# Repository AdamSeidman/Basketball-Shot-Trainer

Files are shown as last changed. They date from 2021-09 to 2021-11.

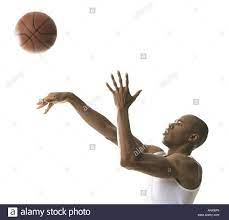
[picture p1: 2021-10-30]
Code/Python_Code/Images/image2.jpg

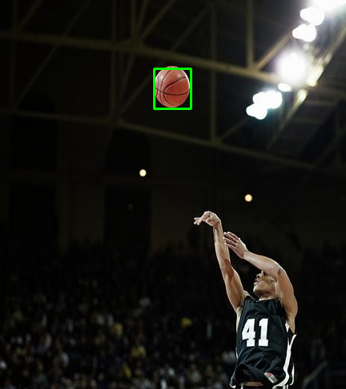
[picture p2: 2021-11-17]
Code/Python_Code/Images/success.PNG

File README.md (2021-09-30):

# Basketball Shot Trainer
**Multidisciplinary Senior Design Project for RIT.** &nbsp; _(P21014)_

&ensp;&ensp;The Unified Sports Basketball Shot Trainer analyzes various parameters of a person’s body while shooting a basketball to determine what can be changed to improve the player’s shooting percentage. It analyzes parameters such as arm trajectory, direction of shot, angle of shot, shooting efforts, etc.

&ensp;&ensp;The goals of the project are to design a device that can accomplish the task of analyzing the parameters as described above and correlate them to shooting performance based on court position.  The desired end-result is a working portable, battery-operated prototype with non-intrusive body sensors that can be modeled for production. The device is to be used by Unified Sports to improve the shot accuracy of basketball players. There are no concerns for intellectual property.

&ensp;&ensp;The aim of this project is to provide an approach to developing players' basketball skills through giving the players tangible feedback on their form and shooting performance. Given that our customer is the Special Olympics Unified Sports league, which gives kids with special needs opportunities to grow, a system that provides feedback for improvement can ultimately help them develop better self-confidence in their abilities.

_See our [Confluence Page](https://wiki.rit.edu/pages/viewpage.action?spaceKey=P21014&title=Project+Overview)_  
&nbsp;

### Our Team: 
| **Member** | **Major** | **Role** | **Contact** |
| --- | :---: | :---: | :---: |
| Matthew Fuss | Electrical Engineering | App Development/Sensor Integration, Documentation | mjf3758@rit.edu |
| Trevor Hess | Mechanical Engineering | Team Leader, Project Management, CAD | tdh8765@rit.edu |
| Mercy Chado | Biomedical Engineering | Systems Engineering, Communication | mxc2597@rit.edu |
| Kaitlyn Pohler | Electrical Engineering | Purchasing | kap3922@rit.edu |
| Adam Seidman | Computer Engineering | Embedded Systems, CAD | ajs1551@rit.edu |
| John Bui | Industrial Engineering | Lean Implementation | jcb2832@rit.edu |

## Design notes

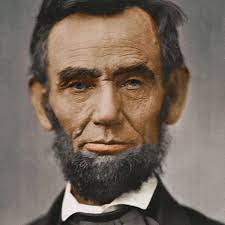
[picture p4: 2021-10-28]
Code/Python_Code/Images/Unknown.jpg

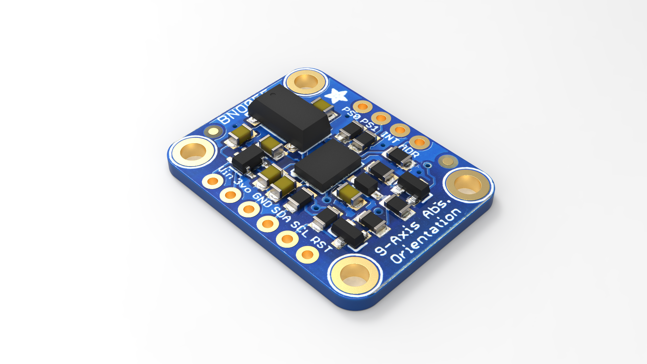
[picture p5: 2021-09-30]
CAD/Adafruit BNO055/Renderings/Render2.png

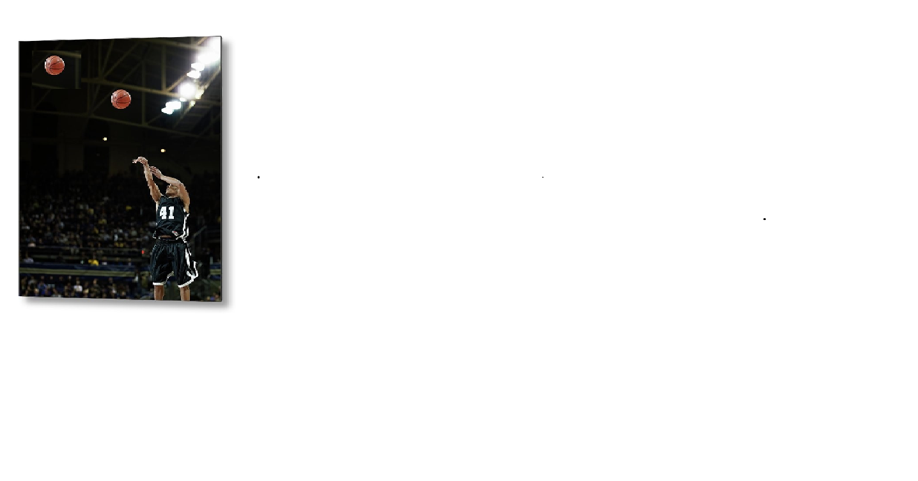
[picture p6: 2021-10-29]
Code/Python_Code/two_balls.png

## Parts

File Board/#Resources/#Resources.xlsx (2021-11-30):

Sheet: Links
BLE Board | https://www.adafruit.com/product/2995
Google Doc | https://docs.google.com/document/d/1nqfAvCQWS0-UqFdw947gi0GywAVGIpcRjdkHSJIjVWc/edit#
Older Feather Pinout | https://cdn-learn.adafruit.com/assets/assets/000/046/196/original/Feather_M0_Basic_Proto_v2.2.pdf?1504805559
Uno (Testing) | https://store-usa.arduino.cc/products/arduino-uno-rev3
Older Feather Power | https://learn.adafruit.com/adafruit-feather-m0-basic-proto/power-management
IMU Info Page | https://learn.adafruit.com/adafruit-bno055-absolute-orientation-sensor/pinouts

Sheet: Relevant Parts
6 pin female | https://www.digikey.com/en/products/detail/amphenol-icc-fci/91614-306ALF/1536169
8 pin female | https://www.digikey.com/en/products/detail/amphenol-icc-fci/91601-308LF/1535152
12 pin female | https://www.digikey.com/en/products/detail/amphenol-icc-fci/91601-412ALF/2713716
6 pin male | https://www.digikey.com/en/products/detail/amphenol-icc-fci/77311-401-06LF/1657857
8 pin male | https://www.digikey.com/en/products/detail/amphenol-icc-fci/68002-208HLF/1878507
12 pin male | (2 6 pins)
10k resistor 0603 | https://www.digikey.com/en/products/detail/nte-electronics-inc/SR1-0603-610/11655708
RGB LED | https://www.digikey.com/en/products/detail/harvatek-corporation/B3803FCH-20C001112U1930/13588742
RGB Resistor | https://www.digikey.com/en/products/detail/panasonic-electronic-components/ERJ-PB3D2000V/6212984
PWR LED | https://www.digikey.com/en/products/detail/american-opto-plus-led/L171L-GC/12325425 | https://www.digikey.com/en/products/detail/sunled/XZCDGK53W-8VF/10449775
PWR Resistor | --- | https://www.digikey.com/en/products/detail/susumu/RR0816P-152-D/432189
Coin Cell Holder | https://www.digikey.com/en/products/detail/keystone-electronics/1027/49724
Coin Cell |  | cr2330 | https://www.digikey.com/en/products/detail/panasonic-bsg/CR2330/107117
Switch | https://www.digikey.com/en/products/detail/nidec-copal-electronics/CFS-0102TA/12142641
4.7uF Cap_16V | https://www.digikey.com/en/products/detail/avx-corporation/TAJA475M016RNJ/808808
1uF Cap 0603 | https://www.digikey.com/en/products/detail/murata-electronics/GRM185R61E105KA12D/5026383
0.1uF Cap 0603 | https://www.digikey.com/product-detail/en/walsin-technology-corporation/0603B104K101CT/1292-1392-1-ND/9355396
5v Regulator | https://www.digikey.com/en/products/detail/texas-instruments/LM1117IMPX-5-0-NOPB/3440161
6 pin IMU cable
6 Pin IMU board | 1 6pin female & male
6 pin IMU Crimps?
6-cable | https://www.digikey.com/en/products/detail/tensility-international-corp/30-00510/6245003
28-wire-red | https://www.digikey.com/en/products/detail/tensility-international-corp/30-01782/13998326
28-wire-black | https://www.digikey.com/en/products/detail/tensility-international-corp/30-01783/13998447

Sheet: Order 1
Vendor: | Digikey |  |  |  | Total: | $46.67
Description | Part # | Price | Quantity | Total |  | Link
6 Pin Female Header | 609-6018-ND | $1.01 | 4 | $4.04 |  | https://www.digikey.com/en/products/detail/amphenol-icc-fci/91601-306LF/1535606
8 Pin Female Header | 609-4966-ND | $1.29 | 2 | $2.58 |  | https://www.digikey.com/en/products/detail/amphenol-icc-fci/91601-308LF/1535152
12 Pin Female Header | 609-4414-1-ND | $2.65 | 2 | $5.30 |  | https://www.digikey.com/en/products/detail/amphenol-icc-fci/91601-412ALF/2713716
6 Pin Male Header | 609-3403-ND | $0.48 | 10 | $4.84 |  | https://www.digikey.com/en/products/detail/amphenol-icc-fci/68001-206HLF/1658017
8 Pin Male Header | 609-10129378-908002BLF-ND | $0.24 | 2 | $0.48 |  | https://www.digikey.com/en/products/detail/amphenol-icc-fci/10129378-908002BLF/7915950
10K Resistor | YAG2321CT-ND | $0.06 | 20 | $1.18 |  | https://www.digikey.com/en/products/detail/yageo/RT0603FRE0710KL/1075040
RGB LED | 3147-B3803FCH-20C001112U1930CT-ND | $0.21 | 4 | $0.84 |  | https://www.digikey.com/en/products/detail/harvatek-corporation/B3803FCH-20C001112U1930/13588742
200 Ohm Resistor | P20201CT-ND | $0.14 | 10 | $1.35 |  | https://www.digikey.com/en/products/detail/panasonic-electronic-components/ERJ-PB3D2000V/6212984
Power LED | 1497-XZCDGK53W-8VFCT-ND | $0.63 | 3 | $1.89 |  | https://www.digikey.com/en/products/detail/sunled/XZCDGK53W-8VF/10449775
1.5K Resistor | RR08P1.5KDCT-ND | $0.09 | 10 | $0.89 |  | https://www.digikey.com/en/products/detail/susumu/RR0816P-152-D/432189
23mm Coin Cell Holder | 36-1027-ND | $1.55 | 2 | $3.10 |  | https://www.digikey.com/en/products/detail/keystone-electronics/1027/49724
CR2330 Batteries | P111-ND | $1.44 | 4 | $5.76 |  | https://www.digikey.com/en/products/detail/panasonic-bsg/CR2330/107117
Power Switch | 563-CFS-0102TACT-ND | $0.79 | 3 | $2.37 |  | https://www.digikey.com/en/products/detail/nidec-copal-electronics/CFS-0102TA/12142641
4.7uF Tantalum Capacitor | 478-8292-1-ND | $0.56 | 3 | $1.68 |  | https://www.digikey.com/en/products/detail/F931D475MAA/478-8292-1-ND/4005673
1uF Capacitor | 490-10021-1-ND | $0.25 | 10 | $2.46 |  | https://www.digikey.com/en/products/detail/murata-electronics/GRM185R61E105KA12D/5026383
0.1uF Capacitor | 1292-1392-1-ND | $0.09 | 10 | $0.92 |  | https://www.digikey.com/product-detail/en/walsin-technology-corporation/0603B104K101CT/1292-1392-1-ND/9355396
5V Regulator | LM1117IMPX-5.0/NOPBCT-ND | $1.41 | 0 | $0.00 |  | https://www.digikey.com/en/products/detail/texas-instruments/LM1117IMPX-5-0-NOPB/3440161
Shipping Estimate | N/a ~ | $6.99 | 1 | $6.99

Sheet: Order 2
Vendor: | Digikey |  |  |  | Total: | $11.66
Description | Part # | Price | Quantity | Total |  | Link
6 Pin Female Header | 609-6018-ND | $1.01 | 2 | $2.02 |  | https://www.digikey.com/en/products/detail/amphenol-icc-fci/91601-306LF/1535606
8 Pin Female Header | 609-4966-ND | $1.29 | 1 | $1.29 |  | https://www.digikey.com/en/products/detail/amphenol-icc-fci/91601-308LF/1535152
12 Pin Female Header | 609-4414-1-ND | $2.65 | 1 | $2.65 |  | https://www.digikey.com/en/products/detail/amphenol-icc-fci/91601-412ALF/2713716
6 Pin Male Header | 609-3403-ND | $0.48 | 1 | $0.48 |  | https://www.digikey.com/en/products/detail/amphenol-icc-fci/68001-206HLF/1658017
23mm Coin Cell Holder | 36-1027-ND | $1.55 | 1 | $1.55 |  | https://www.digikey.com/en/products/detail/keystone-electronics/1027/49724
CR2330 Batteries | P111-ND | $1.44 | 2 | $2.88 |  | https://www.digikey.com/en/products/detail/panasonic-bsg/CR2330/107117
Power Switch | 563-CFS-0102TACT-ND | $0.79 | 1 | $0.79 |  | https://www.digikey.com/en/products/detail/nidec-copal-electronics/CFS-0102TA/12142641

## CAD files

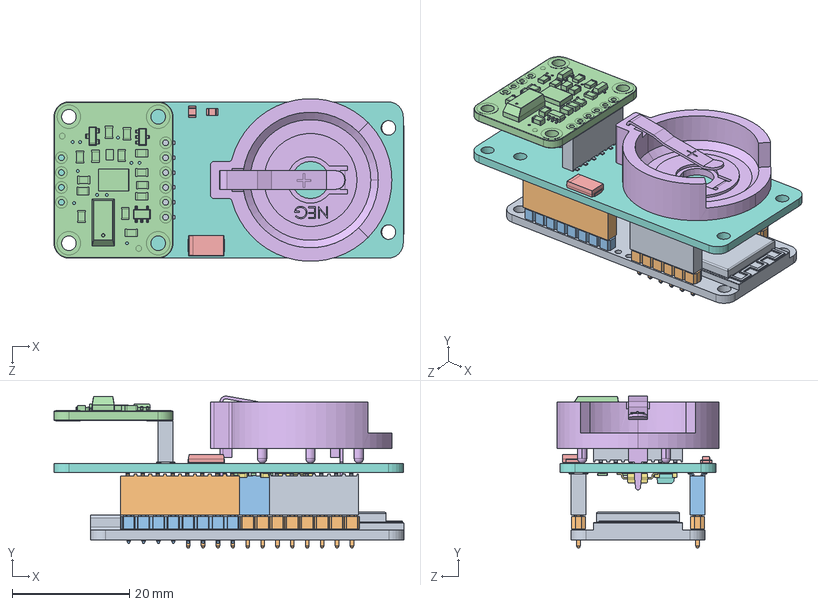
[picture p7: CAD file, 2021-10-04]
CAD/RevC_Electrical_Assembly.SLDASM
59.7 x 25.9 x 27.7 mm
Adafruit M0 AT1500 Feather_000
68001-x06 x 3
p10129378-x08002blf
Adafruit_BNO055
SOLID.step x 2
SOLID-0.step
SOLID-1.step x 4
SOLID-2.step
SOLID-3.step x 2
SOLID-4.step
SOLID-5.step
SOLID-6.step x 7
SOLID-7.step
SOLID-8.step
SOLID-9.step
COMPOUND.step

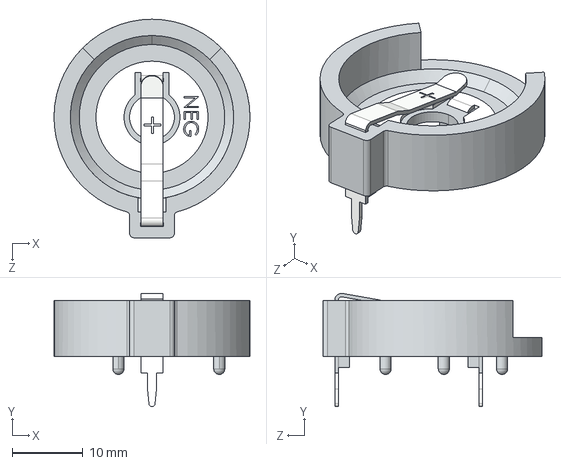
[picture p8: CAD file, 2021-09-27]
Board/#Parts/keystone-PN1027.STEP
27.8 x 16.0 x 31.0 mm

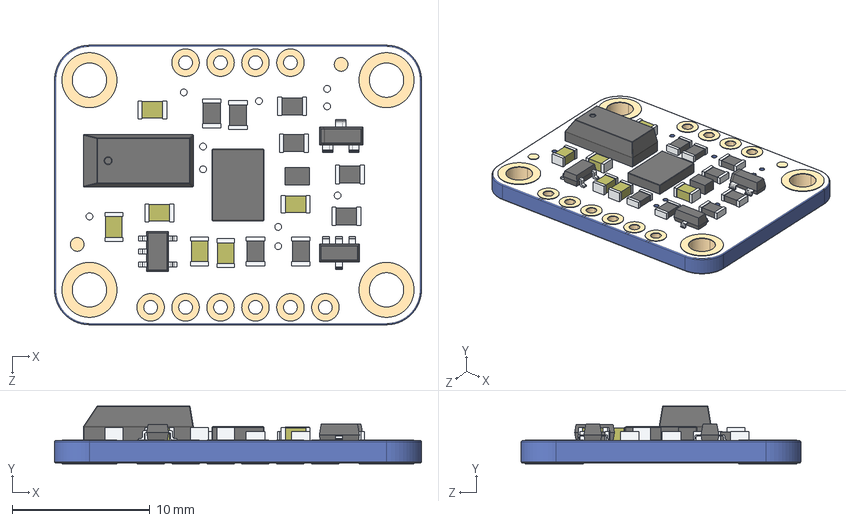
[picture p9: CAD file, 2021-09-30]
CAD/Adafruit BNO055/Adafruit_BNO055_AP214.STEP
26.7 x 4.20 x 20.3 mm

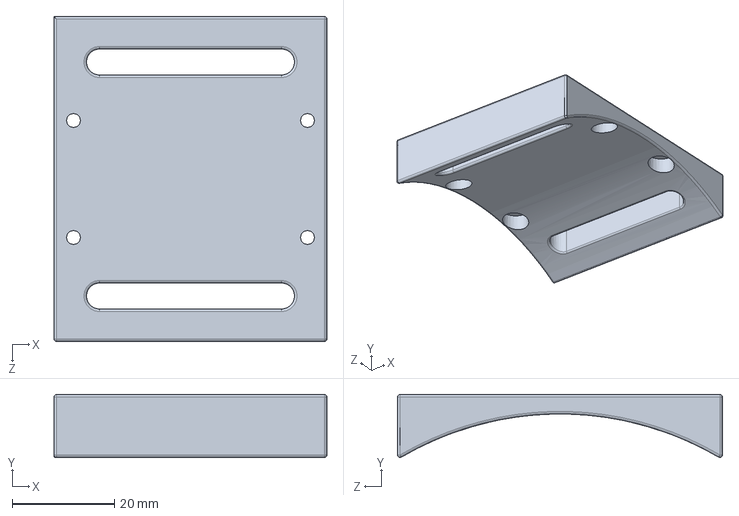
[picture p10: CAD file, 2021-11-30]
CAD/Wearable-R2.SLDPRT
53.3 x 12.3 x 63.5 mm

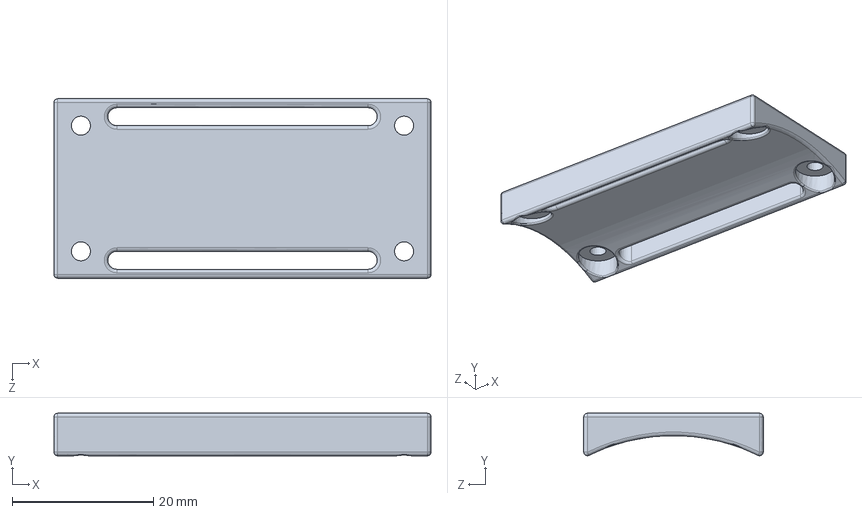
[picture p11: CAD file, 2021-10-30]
Wearable-R0.SLDPRT
53.3 x 6.03 x 25.4 mm

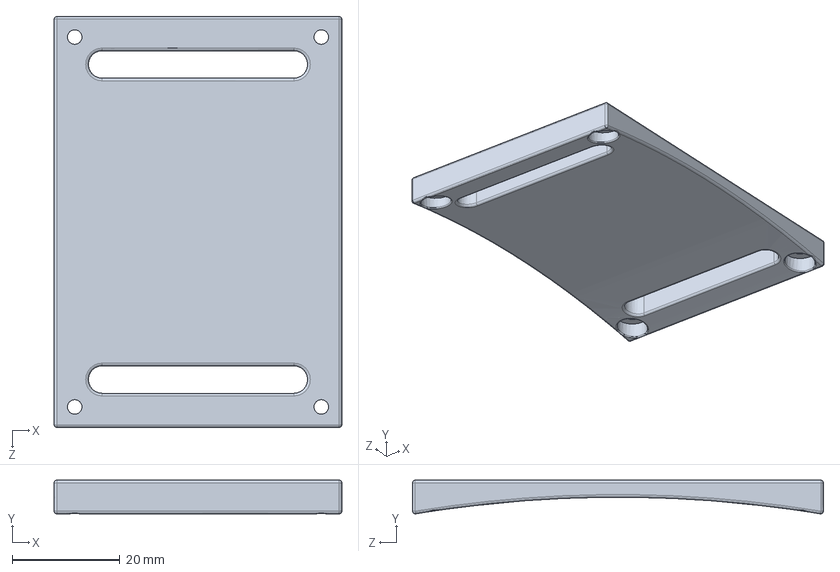
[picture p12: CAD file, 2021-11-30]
CAD/Wearable-R1.SLDPRT
53.3 x 6.26 x 76.2 mm

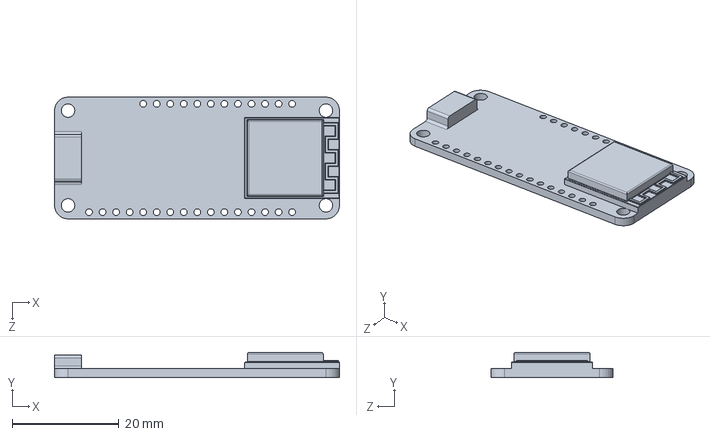
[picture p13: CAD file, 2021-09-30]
CAD/Adafruit M0 AT1500 Feather_000.SLDPRT
53.5 x 4.70 x 22.9 mm

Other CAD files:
CAD/RevC Board STP Files/SOLID-8.step.SLDPRT
CAD/Adafruit BNO055/Adafruit_BNO055_AP203.STEP
CAD/RevC Board STP Files/SOLID-5.step.SLDPRT
CAD/Adafruit BNO055/Adafruit_BNO055.SLDPRT
CAD/RevC Board STP Files/SOLID-1.step.SLDPRT
CAD/RevC Board STP Files/SOLID-0.step.SLDPRT
CAD/RevC Board STP Files/SOLID-9.step.SLDPRT
CAD/RevC Board STP Files/SOLID-7.step.SLDPRT
CAD/RevC Board STP Files/SOLID-6.step.SLDPRT
CAD/RevC Board STP Files/SOLID-4.step.SLDPRT
CAD/RevC Board STP Files/SOLID-3.step.SLDPRT
Board/#Parts/Female Pin Headers 3D/s91601-306lf/91601-306LFc.stp
Board/#Parts/Female Pin Headers 3D/s91601-308lf/91601-308LFc.stp
Board/#Parts/Female Pin Headers 3D/s91601-412alf/91601-412ALFc.stp
CAD/Old SLDPRT Files/Arm_Single - no notch.SLDPRT
CAD/Old SLDPRT Files/Arm_Single.SLDPRT
CAD/Old SLDPRT Files/Example_Plate.SLDPRT
CAD/Old STP Files/Arm_Single.STL
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

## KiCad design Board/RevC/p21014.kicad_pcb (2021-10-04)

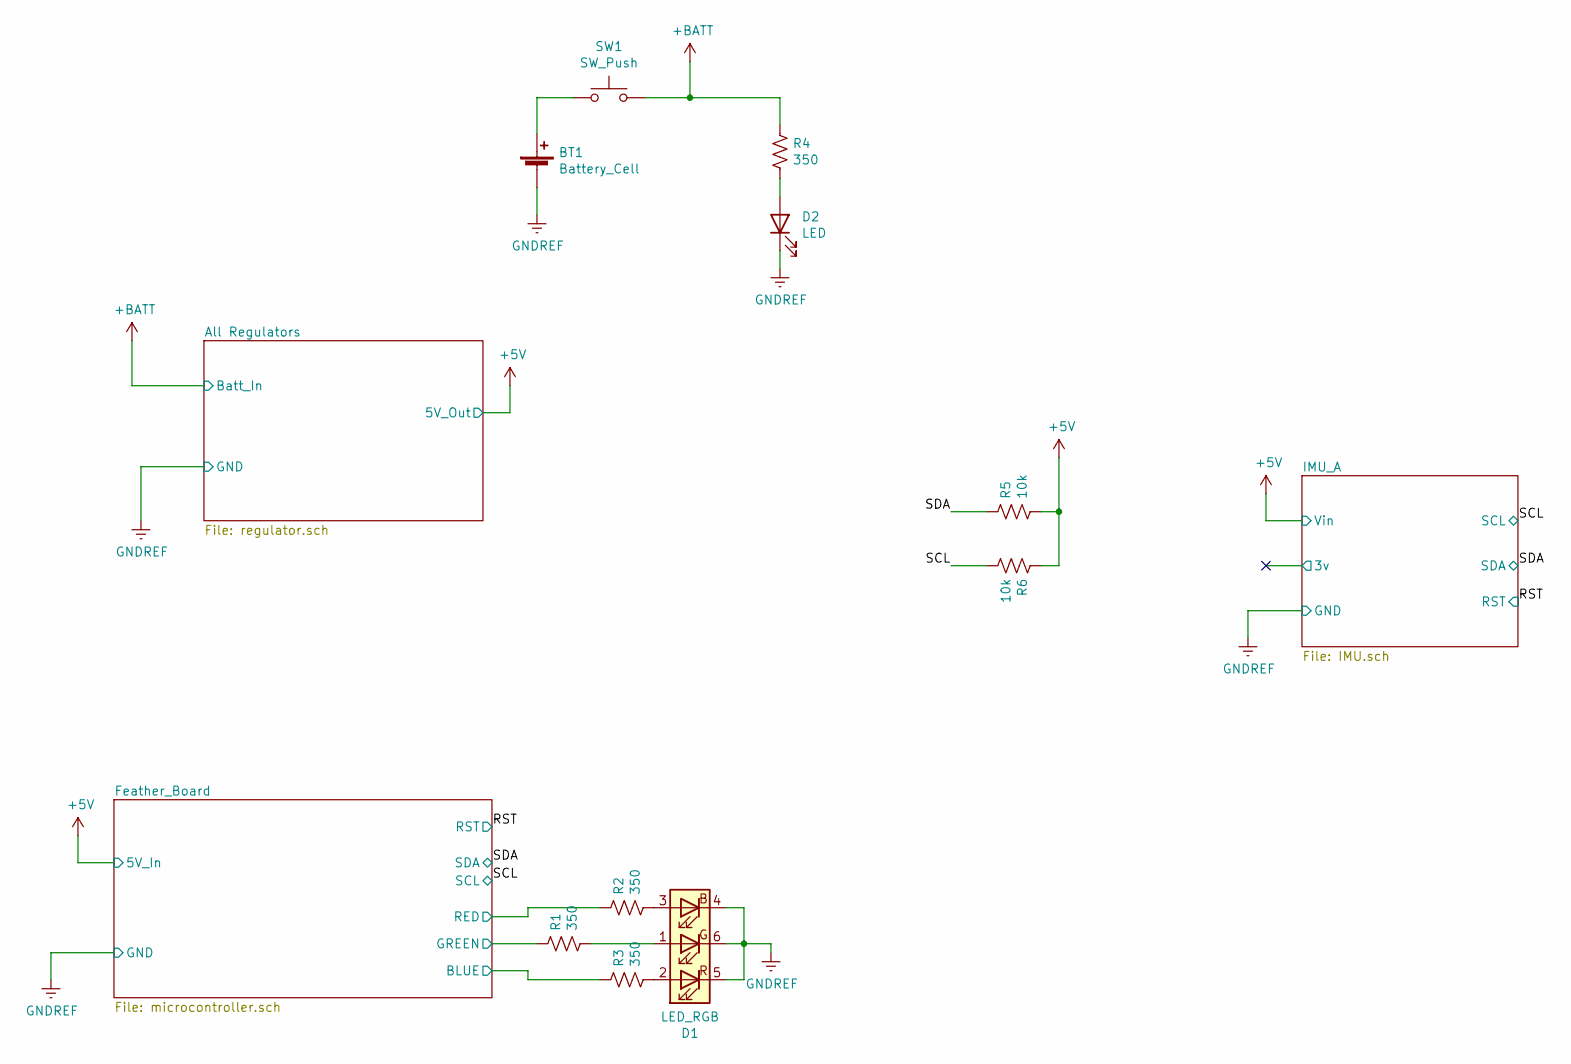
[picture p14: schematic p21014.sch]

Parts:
BT1: Battery_Cell; AJS-Coin-Cell_1062-Digikey
D1: LED_RGB; RGB_AJS
D2: LED; LED_1812_4532Metric
R1, R2, R3, R4: 350; R_0603_1608Metric
R5, R6: 10k; R_0603_1608Metric
SW1: SW_Push; AJS-Switch_CFS-0102TA

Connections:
+5V: R5.2, R6.1; also elsewhere on the board
+BATT: R4.1, SW1.2; also elsewhere on the board
/Feather_Board/BLUE: R3.1; also elsewhere on the board
/Feather_Board/GREEN: R1.1; also elsewhere on the board
/Feather_Board/RED: R2.1; also elsewhere on the board
/SCL: R6.2; also elsewhere on the board
/SDA: R5.1; also elsewhere on the board
GNDREF: BT1.2 (-), D1.4 (BK), D1.5 (RK), D1.6 (GK), D2.1 (K); also elsewhere on the board
unnamed: BT1.1 (+), SW1.1
unnamed: D1.1 (GA), R1.2
unnamed: D1.2 (RA), R3.2
unnamed: D1.3 (BA), R2.2
unnamed: D2.2 (A), R4.2

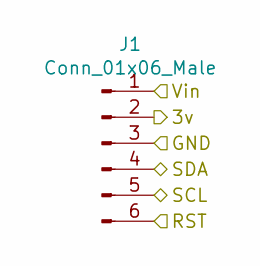
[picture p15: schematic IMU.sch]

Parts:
J1: Conn_01x06_Male; MSD_6_Pin

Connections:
+5V: J1.1; also elsewhere on the board
/IMU_A/3v: J1.2
/RST: J1.6; also elsewhere on the board
/SCL: J1.5; also elsewhere on the board
/SDA: J1.4; also elsewhere on the board
GNDREF: J1.3; also elsewhere on the board

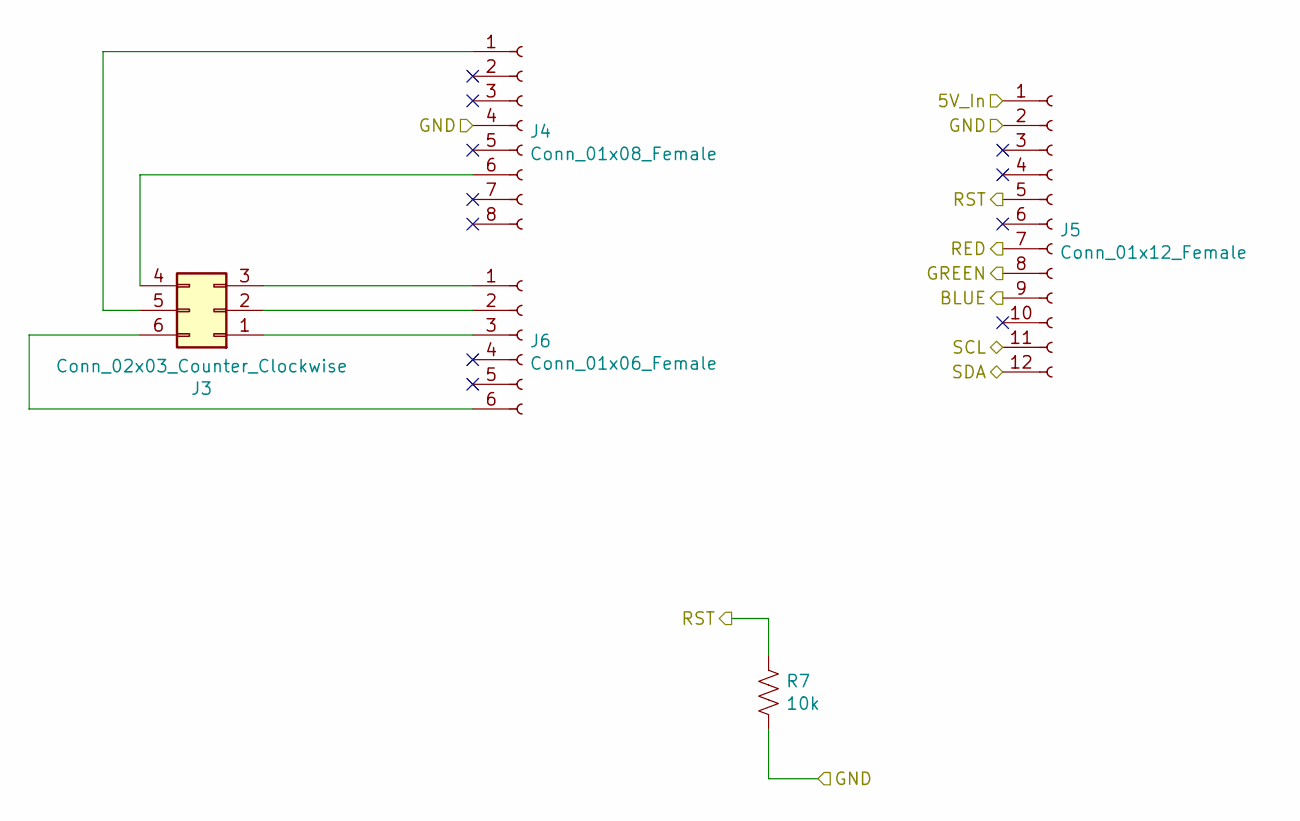
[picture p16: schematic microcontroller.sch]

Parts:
J3: Conn_02x03_Counter_Clockwise; PinHeader_2x03_P2.54mm_Vertical
J4: Conn_01x08_Female; MSD_8_Pin
J5: Conn_01x12_Female; MSD_12_Pin
J6: Conn_01x06_Female; MSD_6_Pin
R7: 10k; R_0603_1608Metric

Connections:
+5V: J5.1; also elsewhere on the board
/Feather_Board/BLUE: J5.9; also elsewhere on the board
/Feather_Board/GREEN: J5.8; also elsewhere on the board
/Feather_Board/RED: J5.7; also elsewhere on the board
/RST: J5.5, R7.1; also elsewhere on the board
/SCL: J5.11; also elsewhere on the board
/SDA: J5.12; also elsewhere on the board
GNDREF: J4.4, J5.2, R7.2; also elsewhere on the board
unnamed: J3.1, J6.3
unnamed: J3.2, J6.2
unnamed: J3.3, J6.1
unnamed: J3.4, J4.6
unnamed: J3.5, J4.1
unnamed: J3.6, J6.6

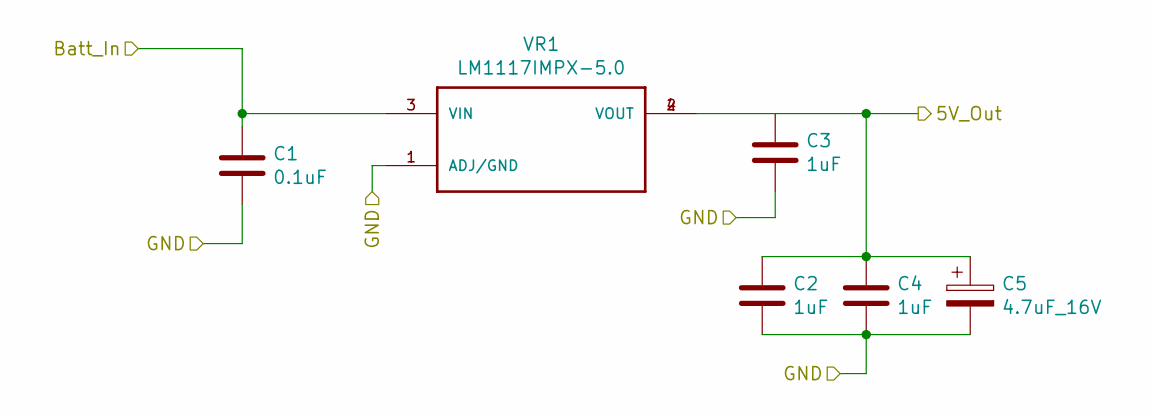
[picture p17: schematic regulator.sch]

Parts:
C1: 0.1uF; C_0603_1608Metric
C2, C3, C4: 1uF; C_0603_1608Metric
C5: 4.7uF_16V; CP_EIA-3216-18_Kemet-A
VR1: LM1117IMPX-5.0; SOT230P700X180-4N

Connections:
+5V: C2.1, C4.1, C5.1, VR1.2 (VOUT), VR1.4 (VOUT); also elsewhere on the board
+BATT: C1.1, VR1.3 (VIN); also elsewhere on the board
GNDREF: C1.2, C2.2, C3.2, C4.2, C5.2, VR1.1 (ADJ/GND); also elsewhere on the board

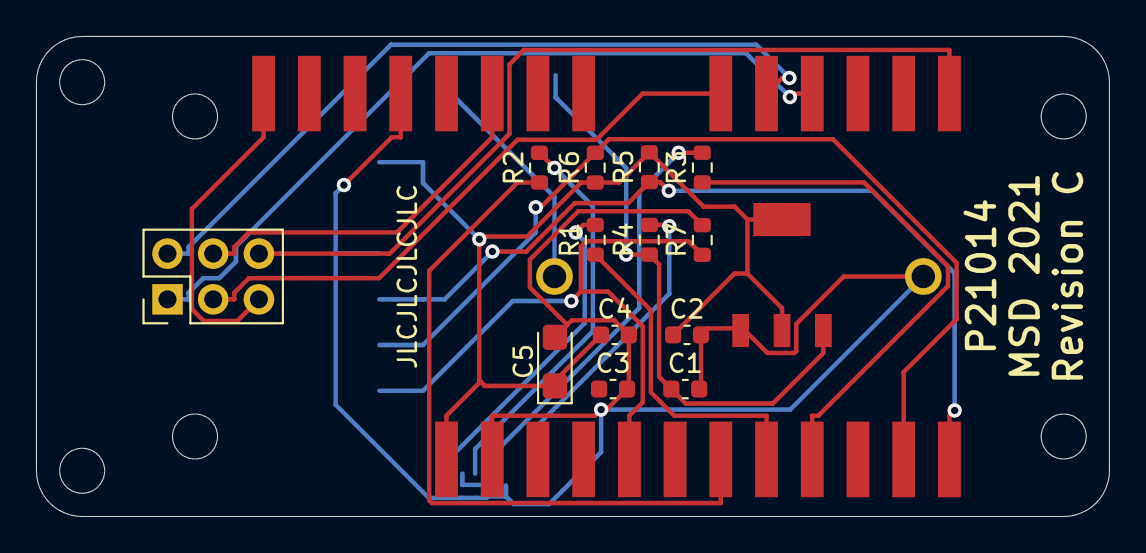
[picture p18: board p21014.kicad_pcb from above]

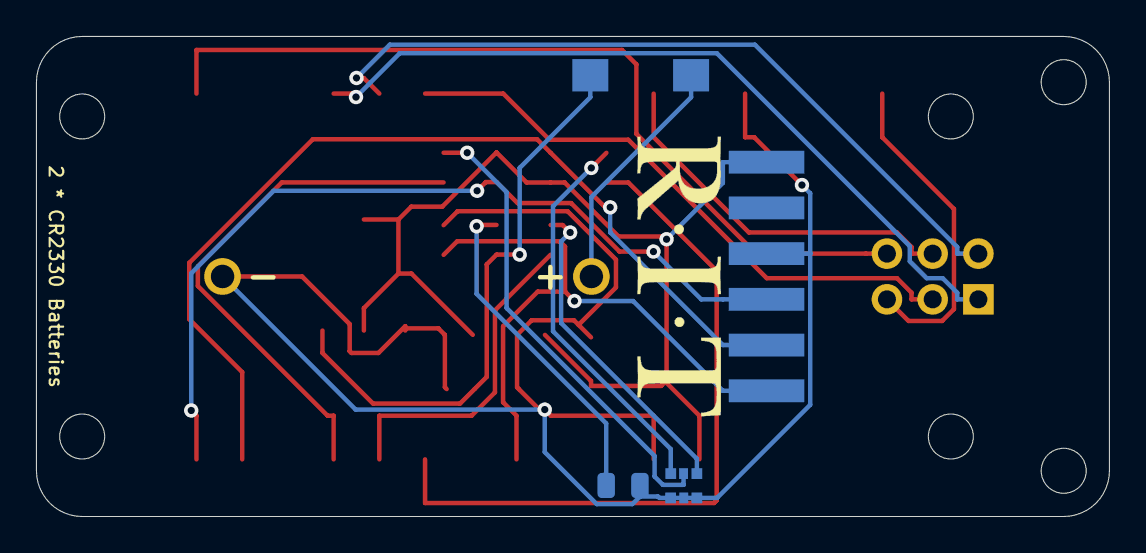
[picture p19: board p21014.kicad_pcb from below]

Board: 2 copper layers, 59.6 x 26.7 mm, 29 parts (6 on the bottom side), 20 nets.

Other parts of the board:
G55: LOGO; RIT_Logo
MH1, MH2, MH3, MH4, MH5, MH6: MountingHole_2.5mm

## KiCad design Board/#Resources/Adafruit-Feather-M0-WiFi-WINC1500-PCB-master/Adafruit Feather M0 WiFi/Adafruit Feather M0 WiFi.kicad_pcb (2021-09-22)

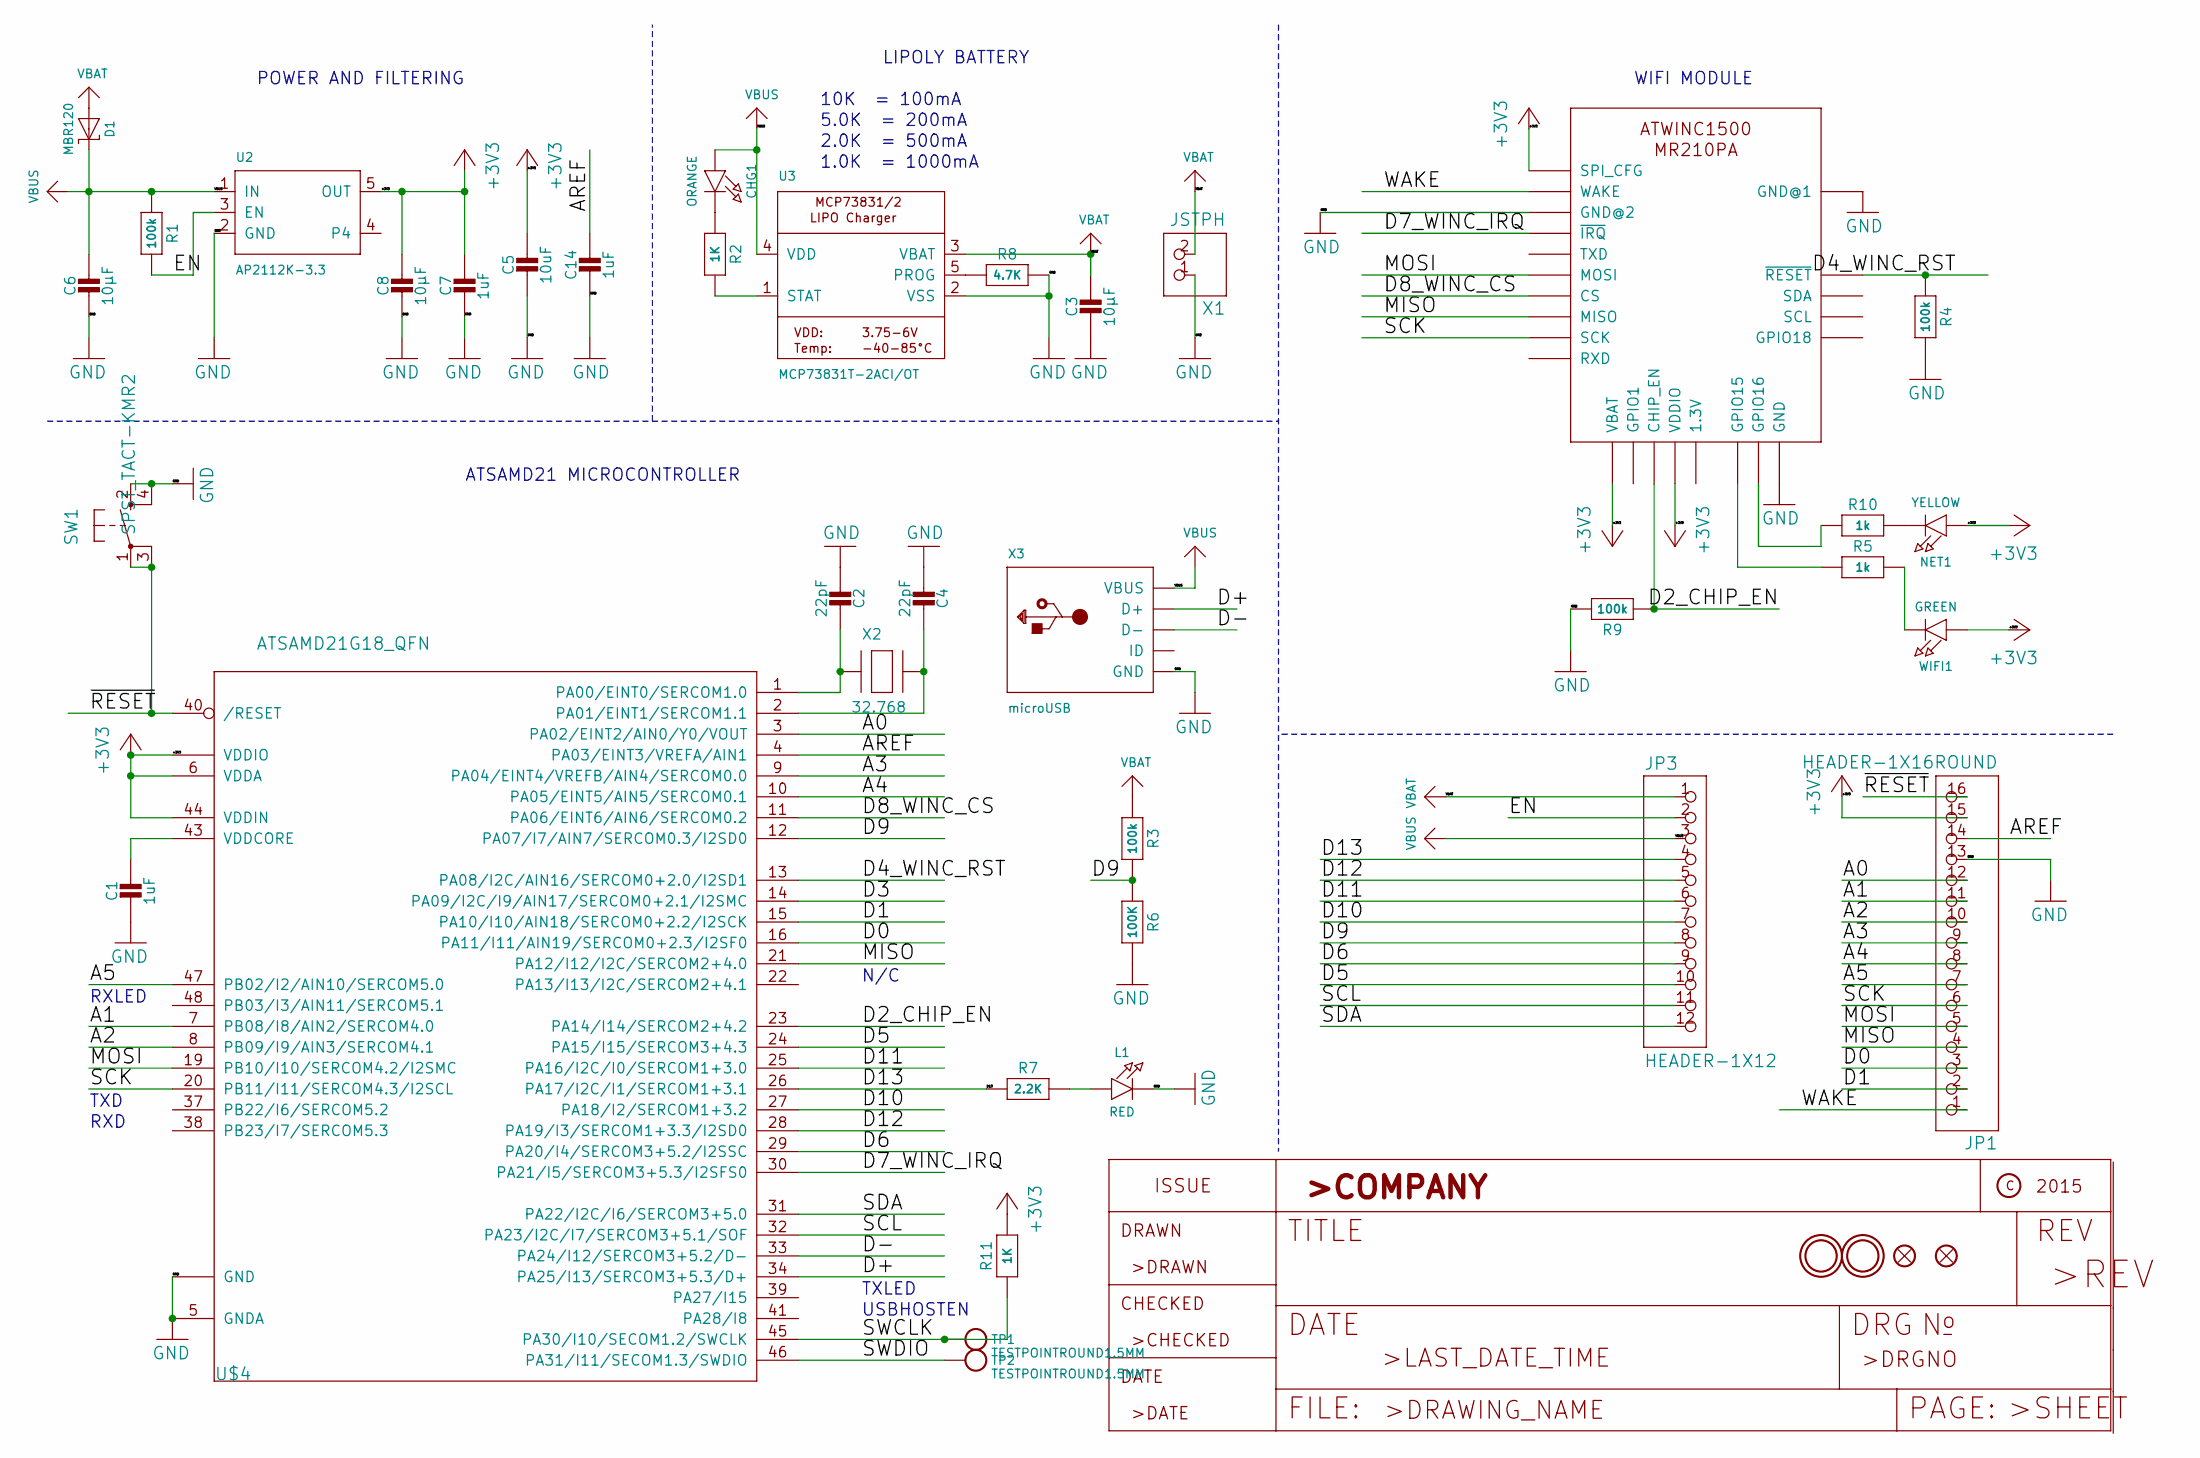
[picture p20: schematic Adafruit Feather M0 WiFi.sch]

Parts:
C1, C7, C14: 1uF; 0603-NO
C2, C4: 22pF; 0603-NO
C3, C6, C8: 10µF; 0805-NO
C5: 10uF; 0805-NO
CHG1: ORANGE; CHIPLED_0805_NOOUTLINE
D1: MBR120; SOD-123
JP1: HEADER-1X16ROUND; 1X16_ROUND
JP3: HEADER-1X12; 1X12_ROUND
L1: RED; CHIPLED_0805_NOOUTLINE
NET1: YELLOW; CHIPLED_0805_NOOUTLINE
R1, R3, R4, R9: 100k; 0603-NO
R2, R11: 1K; 0603-NO
R5, R10: 1k; 0603-NO
R6: 100K; 0603-NO
R7: 2.2K; 0603-NO
R8: 4.7K; 0603-NO
SW1: SPST_TACT-KMR2; KMR2
TP1, TP2: TESTPOINTROUND1.5MM; TESTPOINT_ROUND_1.5MM
U2: AP2112K-3.3; SOT23-5
U3: MCP73831T-2ACI/OT; SOT23-5
U$4: ATSAMD21G18_QFN; TQFN48_7MM
U$31, U$32: MOUNTINGHOLE2.5; MOUNTINGHOLE_2.5_PLATED
U$34, U$35: FIDUCIAL\"\"; FIDUCIAL_1MM
WIFI1: GREEN; CHIPLED_0805_NOOUTLINE
X1: JSTPH; JSTPH2
X2: 32.768; XTAL3215
X3: microUSB; 4UCONN_20329_V2
X4: ATWINC1500_MR210PA

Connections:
+3V3: C5.1, C7.1, C8.1, JP1.15, NET1.A, R11.2, U2.5 (OUT), U$4.6 (VDDA), U$4.17 (VDDIO), U$4.36 (VDDIO), U$4.44 (VDDIN), WIFI1.A, X4.J10 (SPI_CFG), X4.J20 (VBAT), X4.J23 (VDDIO)
/A0: JP1.12, U$4.3 (PA02/EINT2/AIN0/Y0/VOUT)
/A1: JP1.11, U$4.7 (PB08/I8/AIN2/SERCOM4.0)
/A2: JP1.10, U$4.8 (PB09/I9/AIN3/SERCOM4.1)
/A3: JP1.9, U$4.9 (PA04/EINT4/VREFB/AIN4/SERCOM0.0)
/A4: JP1.8, U$4.10 (PA05/EINT5/AIN5/SERCOM0.1)
/A5: JP1.7, U$4.47 (PB02/I2/AIN10/SERCOM5.0)
/AREF: C14.1, JP1.14, U$4.4 (PA03/EINT3/VREFA/AIN1)
/D0: JP1.3, U$4.16 (PA11/I11/AIN19/SERCOM0+2.3/I2SF0)
/D1: JP1.2, U$4.15 (PA10/I10/AIN18/SERCOM0+2.2/I2SCK)
/D2_CHIP_EN: R9.1, U$4.23 (PA14/I14/SERCOM2+4.2), X4.J22 (CHIP_EN)
/D3: U$4.14 (PA09/I2C/I9/AIN17/SERCOM0+2.1/I2SMC)
/D4_WINC_RST: R4.1, U$4.13 (PA08/I2C/AIN16/SERCOM0+2.0/I2SD1), X4.J4 (~RESET)
/D5: JP3.10, U$4.24 (PA15/I15/SERCOM3+4.3)
/D6: JP3.9, U$4.29 (PA20/I4/SERCOM3+5.2/I2SSC)
/D7_WINC_IRQ: U$4.30 (PA21/I5/SERCOM3+5.3/I2SFS0), X4.J13 (~IRQ)
/D8_WINC_CS: U$4.11 (PA06/EINT6/AIN6/SERCOM0.2), X4.J16 (CS)
/D9: JP3.8, R3.2, R6.1, U$4.12 (PA07/I7/AIN7/SERCOM0.3/I2SD0)
/D10: JP3.7, U$4.27 (PA18/I2/SERCOM1+3.2)
/D11: JP3.6, U$4.25 (PA16/I2C/I0/SERCOM1+3.0)
/D12: JP3.5, U$4.28 (PA19/I3/SERCOM1+3.3/I2SD0)
/D13: JP3.4, R7.1, U$4.26 (PA17/I2C/I1/SERCOM1+3.1)
/D+: U$4.34 (PA25/I13/SERCOM3+5.3/D+), X3.D+
/D-: U$4.33 (PA24/I12/SERCOM3+5.2/D-), X3.D-
/EN: JP3.2, R1.2, U2.3 (EN)
/MISO: JP1.4, U$4.21 (PA12/I12/I2C/SERCOM2+4.0), X4.J17 (MISO)
/MOSI: JP1.5, U$4.19 (PB10/I10/SERCOM4.2/I2SMC), X4.J15 (MOSI)
/SCK: JP1.6, U$4.20 (PB11/I11/SERCOM4.3/I2SCL), X4.J18 (SCK)
/SCL: JP3.11, U$4.32 (PA23/I2C/I7/SERCOM3+5.1/SOF)
/SDA: JP3.12, U$4.31 (PA22/I2C/I6/SERCOM3+5.0)
/SWCLK: R11.1, TP1.P$1, U$4.45 (PA30/I10/SECOM1.2/SWCLK)
/SWDIO: TP2.P$1, U$4.46 (PA31/I11/SECOM1.3/SWDIO)
/WAKE: JP1.1, X4.J11 (WAKE)
/~RESET: JP1.16, SW1.1, SW1.3 (P1), U$4.40 (/RESET)
GND: C1.2, C2.2, C3.2, C4.2, C5.2, C6.2, C7.2, C8.2, C14.2, JP1.13, L1.C, R4.2, R6.2, R8.2, R9.2, SW1.2 (S), SW1.4 (S1), U2.2 (GND), U3.2 (VSS), U$4.5 (GNDA), U$4.18 (GND), U$4.35 (GND), U$4.42 (GND), U$4.THERMAL (GND), X1.1, X3.BASE@1 (GND), X3.BASE@2 (GND), X3.GND, X3.SPRT@1 (GND), X3.SPRT@2 (GND), X3.SPRT@3 (GND), X3.SPRT@4 (GND), X4.J9 (GND@1), X4.J12 (GND@2), X4.J28 (GND), X4.MTGND (GND)
unnamed: C1.1, U$4.43 (VDDCORE)
unnamed: C2.1, U$4.1 (PA00/EINT0/SERCOM1.0), X2.P$1
unnamed: C4.1, U$4.2 (PA01/EINT1/SERCOM1.1), X2.P$2
unnamed: CHG1.C, R2.1
unnamed: L1.A, R7.2
unnamed: NET1.C, R10.2
unnamed: R2.2, U3.1 (STAT)
unnamed: R5.1, X4.J26 (GPIO15)
unnamed: R5.2, WIFI1.C
unnamed: R8.1, U3.5 (PROG)
unnamed: R10.1, X4.J27 (GPIO16)
VBAT: C3.1, D1.A, JP3.1, R3.1, U3.3 (VBAT), X1.2
VBUS: C6.1, CHG1.A, D1.C, JP3.3, R1.1, U2.1 (IN), U3.4 (VDD), X3.VBUS

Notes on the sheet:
POWER AND FILTERING
10K = 100mA
5.0K = 200mA
2.0K = 500mA
1.0K = 1000mA
N/C
TXLED
USBHOSTEN
RXLED
TXD
RXD
LIPOLY BATTERY
WIFI MODULE
ATSAMD21 MICROCONTROLLER

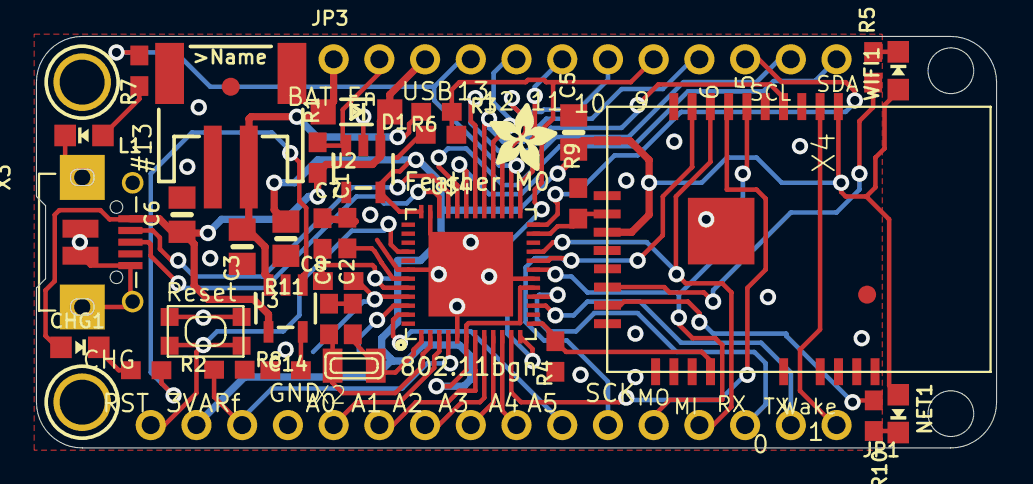
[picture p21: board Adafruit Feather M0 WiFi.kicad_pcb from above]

Board: 2 copper layers, 53.3 x 22.9 mm, 47 parts (0 on the bottom side), 47 nets.

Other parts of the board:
@HOLE0, @HOLE1: (no value)
U$7, U$12: ADAFRUIT_3.5MM
U$9: FEATHERLOGO
U$13: PCBFEAT-REV-040

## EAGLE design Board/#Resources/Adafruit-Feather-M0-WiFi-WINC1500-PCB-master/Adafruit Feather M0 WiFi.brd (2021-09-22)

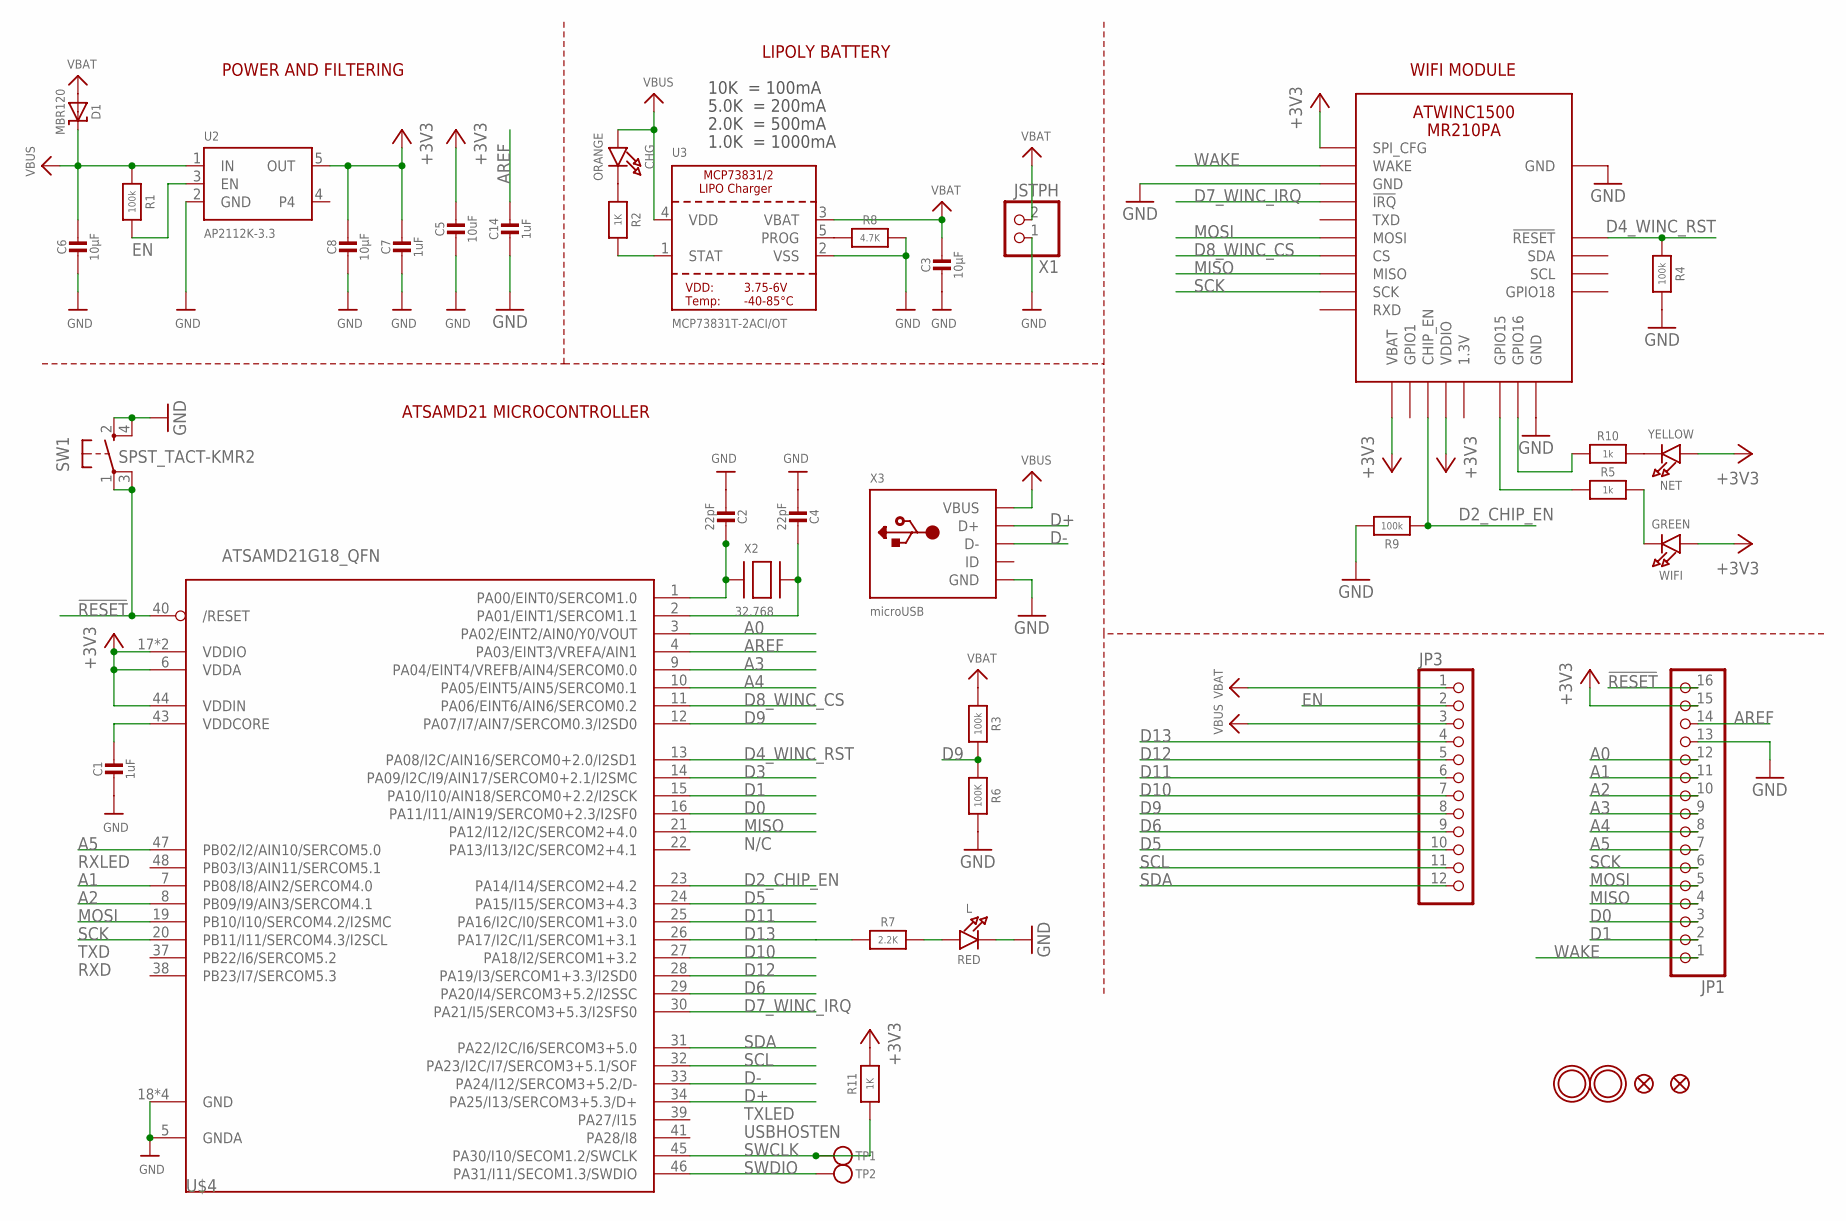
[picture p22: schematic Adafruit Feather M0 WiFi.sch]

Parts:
C1, C7, C14: 1uF; 0603-NO
C2, C4: 22pF; 0603-NO
C3, C6, C8: 10µF; 0805-NO
C5: 10uF; 0805-NO
CHG: ORANGE; CHIPLED_0805_NOOUTLINE
D1: MBR120; SOD-123
JP1: HEADER-1X16ROUND; 1X16_ROUND
JP3: HEADER-1X12; 1X12_ROUND
L: RED; CHIPLED_0805_NOOUTLINE
NET: YELLOW; CHIPLED_0805_NOOUTLINE
R1, R3, R4, R9: 100k; 0603-NO
R2, R11: 1K; 0603-NO
R5, R10: 1k; 0603-NO
R6: 100K; 0603-NO
R7: 2.2K; 0603-NO
R8: 4.7K; 0603-NO
SW1: SPST_TACT-KMR2; KMR2
TP1, TP2: TESTPOINTROUND1.5MM; TESTPOINT_ROUND_1.5MM
U2: AP2112K-3.3; SOT23-5
U3: MCP73831T-2ACI/OT; SOT23-5
U$4: ATSAMD21G18_QFN; TQFN48_7MM
U$31, U$32: MOUNTINGHOLE2.5; MOUNTINGHOLE_2.5_PLATED
U$34, U$35: FIDUCIAL""; FIDUCIAL_1MM
WIFI: GREEN; CHIPLED_0805_NOOUTLINE
X1: JSTPH; JSTPH2
X2: 32.768; XTAL3215
X3: microUSB; 4UCONN_20329_V2
X4: ATWINC1500_MR210PA

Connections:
!RESET: JP1.16, SW1.1, SW1.3 (P1), U$4.40 (/RESET)
+3V3: C5.1, C7.1, C8.1, JP1.15, NET.A, R11.2, U2.5 (OUT), U$4.6 (VDDA), U$4.17 (VDDIO), U$4.36 (VDDIO), U$4.44 (VDDIN), WIFI.A, X4.J10 (SPI_CFG), X4.J20 (VBAT), X4.J23 (VDDIO)
A0: JP1.12, U$4.3 (PA02/EINT2/AIN0/Y0/VOUT)
A1: JP1.11, U$4.7 (PB08/I8/AIN2/SERCOM4.0)
A2: JP1.10, U$4.8 (PB09/I9/AIN3/SERCOM4.1)
A3: JP1.9, U$4.9 (PA04/EINT4/VREFB/AIN4/SERCOM0.0)
A4: JP1.8, U$4.10 (PA05/EINT5/AIN5/SERCOM0.1)
A5: JP1.7, U$4.47 (PB02/I2/AIN10/SERCOM5.0)
AREF: C14.1, JP1.14, U$4.4 (PA03/EINT3/VREFA/AIN1)
D0: JP1.3, U$4.16 (PA11/I11/AIN19/SERCOM0+2.3/I2SF0)
D1: JP1.2, U$4.15 (PA10/I10/AIN18/SERCOM0+2.2/I2SCK)
D2_CHIP_EN: R9.1, U$4.23 (PA14/I14/SERCOM2+4.2), X4.J22 (CHIP_EN)
D3: U$4.14 (PA09/I2C/I9/AIN17/SERCOM0+2.1/I2SMC)
D4_WINC_RST: R4.1, U$4.13 (PA08/I2C/AIN16/SERCOM0+2.0/I2SD1), X4.J4 (!RESET)
D5: JP3.10, U$4.24 (PA15/I15/SERCOM3+4.3)
D6: JP3.9, U$4.29 (PA20/I4/SERCOM3+5.2/I2SSC)
D7_WINC_IRQ: U$4.30 (PA21/I5/SERCOM3+5.3/I2SFS0), X4.J13 (!IRQ)
D8_WINC_CS: U$4.11 (PA06/EINT6/AIN6/SERCOM0.2), X4.J16 (CS)
D9: JP3.8, R3.2, R6.1, U$4.12 (PA07/I7/AIN7/SERCOM0.3/I2SD0)
D10: JP3.7, U$4.27 (PA18/I2/SERCOM1+3.2)
D11: JP3.6, U$4.25 (PA16/I2C/I0/SERCOM1+3.0)
D12: JP3.5, U$4.28 (PA19/I3/SERCOM1+3.3/I2SD0)
D13: JP3.4, R7.1, U$4.26 (PA17/I2C/I1/SERCOM1+3.1)
D+: U$4.34 (PA25/I13/SERCOM3+5.3/D+), X3.D+
D-: U$4.33 (PA24/I12/SERCOM3+5.2/D-), X3.D-
EN: JP3.2, R1.2, U2.3 (EN)
GND: C1.2, C2.2, C3.2, C4.2, C5.2, C6.2, C7.2, C8.2, C14.2, JP1.13, L.C, R4.2, R6.2, R8.2, R9.2, SW1.2 (S), SW1.4 (S1), U2.2 (GND), U3.2 (VSS), U$4.5 (GNDA), U$4.18 (GND), U$4.35 (GND), U$4.42 (GND), U$4.THERMAL (GND), X1.1, X3.BASE@1 (GND), X3.BASE@2 (GND), X3.GND, X3.SPRT@1 (GND), X3.SPRT@2 (GND), X3.SPRT@3 (GND), X3.SPRT@4 (GND), X4.J9 (GND), X4.J12 (GND), X4.J28 (GND), X4.MTGND (GND)
MISO: JP1.4, U$4.21 (PA12/I12/I2C/SERCOM2+4.0), X4.J17 (MISO)
MOSI: JP1.5, U$4.19 (PB10/I10/SERCOM4.2/I2SMC), X4.J15 (MOSI)
unnamed: CHG.C, R2.1
unnamed: L.A, R7.2
unnamed: R2.2, U3.1 (STAT)
unnamed: R8.1, U3.5 (PROG)
unnamed: C2.1, U$4.1 (PA00/EINT0/SERCOM1.0), X2.P$1
unnamed: R5.1, X4.J26 (GPIO15)
unnamed: C4.1, U$4.2 (PA01/EINT1/SERCOM1.1), X2.P$2
unnamed: R10.1, X4.J27 (GPIO16)
unnamed: R5.2, WIFI.C
unnamed: NET.C, R10.2
SCK: JP1.6, U$4.20 (PB11/I11/SERCOM4.3/I2SCL), X4.J18 (SCK)
SCL: JP3.11, U$4.32 (PA23/I2C/I7/SERCOM3+5.1/SOF)
SDA: JP3.12, U$4.31 (PA22/I2C/I6/SERCOM3+5.0)
SWCLK: R11.1, TP1.P$1, U$4.45 (PA30/I10/SECOM1.2/SWCLK)
SWDIO: TP2.P$1, U$4.46 (PA31/I11/SECOM1.3/SWDIO)
VBAT: C3.1, D1.A, JP3.1, R3.1, U3.3 (VBAT), X1.2
VBUS: C6.1, CHG.A, D1.C, JP3.3, R1.1, U2.1 (IN), U3.4 (VDD), X3.VBUS
VDDCORE: C1.1, U$4.43 (VDDCORE)
WAKE: JP1.1, X4.J11 (WAKE)

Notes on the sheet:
POWER AND FILTERING
10K = 100mA
5.0K = 200mA
2.0K = 500mA
1.0K = 1000mA
N/C
TXLED
USBHOSTEN
RXLED
TXD
RXD
LIPOLY BATTERY
WIFI MODULE
ATSAMD21 MICROCONTROLLER

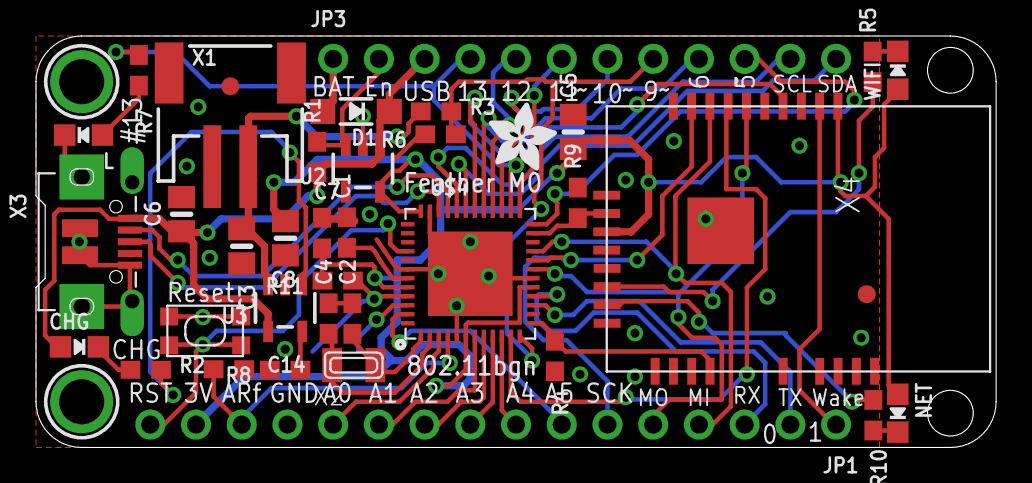
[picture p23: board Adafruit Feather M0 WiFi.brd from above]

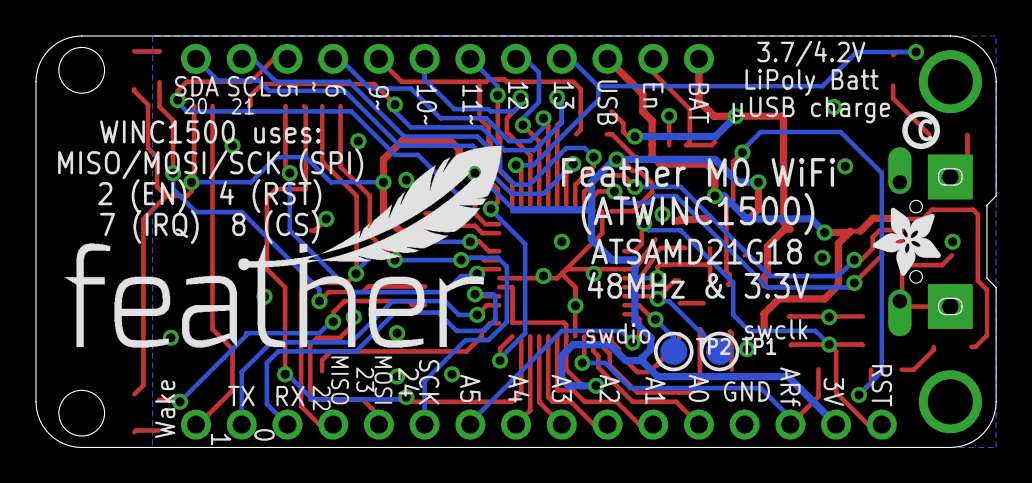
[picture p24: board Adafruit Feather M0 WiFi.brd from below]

Board: 2 copper layers, 53.3 x 22.9 mm, 45 parts (5 on the bottom side), 47 nets.

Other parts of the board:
U$7, U$12: ADAFRUIT_3.5MM
U$9: FEATHERLOGO
U$13: PCBFEAT-REV-040

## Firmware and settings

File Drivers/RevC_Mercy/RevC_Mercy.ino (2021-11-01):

/**
 * P21014 Wearable Bluetooth Module Driver
 * Uses Feather M0 Bluefruit BLE, Adafruit BNO055, and Custom PCB/Mounting
 * Author: Adam Seidman
 */

#include "ShotTrainer.h"
#include "LEDs.h"
#include <avr/dtostrf.h>

// Bluetooth/Sensor Objects
Adafruit_BluefruitLE_SPI ble(BLUEFRUIT_SPI_CS, BLUEFRUIT_SPI_IRQ, BLUEFRUIT_SPI_RST);
Adafruit_BNO055 bno = Adafruit_BNO055(I2C_PORT);

// Global Variables
char _buffer[128];
long last_time = 0;
sensors_event_t event;
bool is_sending = false;

void setup(void)
{
  configure_leds();

  Serial.begin(BAUD_RATE);
  Serial.println( F("Basketball Shot Trainer- Arm Module: Serial Output") );
  Serial.println( F("--------------------------------------------------\n\r") );

  configure_imu();
  configure_bluetooth();

  wait_for_connection();
  last_time = millis();
}

void loop(void)
{
  if ( !ble.isConnected() )
  {
    Serial.println( F("Lost Bluetooth Connection.") );
    wait_for_connection();
  }

  if ( millis() >= (last_time + WAIT_TIME) )
  {
    bno.getEvent(&event);

    send_data(event.orientation.x, event.orientation.y, event.orientation.z);

    last_time = millis();
  }
}

char xBuf[32];
char yBuf[32];
char zBuf[32];

void send_data(float raw_data_x, float raw_data_y, float raw_data_z)
{  
  ble.print(TX_COMMAND);

  dtostrf(raw_data_x, 1, 2, xBuf);
  dtostrf(raw_data_y, 1, 2, yBuf);
  dtostrf(raw_data_z, 1, 2, zBuf);

  sprintf(_buffer, "X: %s, Y: %s, Z: %s\n\r", xBuf, yBuf, zBuf);

  ble.println(_buffer);

  // check response stastus
  if ( !ble.waitForOK() ) Serial.println( F("Failed to send a packet.\n\r") );
}

void configure_leds(void)
{
  pinMode(RED_PIN, OUTPUT);
  pinMode(GREEN_PIN, OUTPUT);
  pinMode(BLUE_PIN, OUTPUT);

  setLedColor(INIT);
}

void configure_imu(void)
{
  Serial.print( F("Initializing the BNO055 IMU module: ") );

  if ( !bno.begin() ) error( F("Oops, no BNO055 detected ... Check your wiring or I2C ADDR!") );
  
  delay(1000);

  bno.setExtCrystalUse(true);
  Serial.println( F("OK!") );
}

void configure_bluetooth(void)
{
  /* Initialise the module */
  Serial.print( F("Initializing the Bluefruit LE module: ") );

  if ( !ble.begin(false) )   error( F("Couldn't find Bluefruit, make sure it's in Command mode & check wiring?") );
  Serial.println( F("OK!") );

  /* Disable command echo from Bluefruit */
  ble.echo(false);

  if ( FACTORYRESET_ENABLE )
  {
    /* Perform a factory reset to make sure everything is in a known state */
    Serial.print( F("Performing a factory reset: ") );
    if ( !ble.factoryReset() )
    {
      error( F("Couldn't factory reset") );
    }
    else
    {
      Serial.println( F("OK!") );
    }
  }

  ble.println(DEVICE_NAME_COMMAND);   // Set Device Name
}

void setLedColor(uint8_t color)
{  
  digitalWrite(RED_PIN, (color >> RED_BIT) & COLOR_MSK);
  digitalWrite(GREEN_PIN, (color >> GREEN_BIT) & COLOR_MSK);
  digitalWrite(BLUE_PIN, (color >> BLUE_BIT) & COLOR_MSK);
}

void wait_for_connection(void)
{
  setLedColor(AWAIT_CONN);
  Serial.println( F("\n\rWaiting for connection...") );
  is_sending = false;
  while ( !ble.isConnected() )  delay(500);
  Serial.println( F("Connected!\n\r") );
  setLedColor(NORMAL);
}

void error(const __FlashStringHelper*err)
{
  Serial.println("");
  Serial.println(err);
  setLedColor(ERR);
  while (1);
}

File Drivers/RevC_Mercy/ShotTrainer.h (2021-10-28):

#ifndef  __shot_trainer__
#define  __shot_trainer__

// Adafruit Bluetooth Includes
#include <Adafruit_ATParser.h>
#include <Adafruit_BLE.h>
#include <Adafruit_BLEBattery.h>
#include <Adafruit_BLEEddystone.h>
#include <Adafruit_BLEGatt.h>
#include <Adafruit_BLEMIDI.h>
#include <Adafruit_BluefruitLE_SPI.h>
#include <Adafruit_BluefruitLE_UART.h>
#include <Adafruit_BLE_UART.h>
#include <Arduino.h>
#include <SPI.h>
#include "Adafruit_BLE.h"
#include "Adafruit_BluefruitLE_SPI.h"
#include "Adafruit_BluefruitLE_UART.h"

// BNO055 Sensor Includes
#include <Wire.h>
#include <Adafruit_Sensor.h>
#include <Adafruit_BNO055.h>
#include <utility/imumaths.h>

// BLEUART PROPERTIES
#define  FACTORYRESET_ENABLE          1

// BLE COMMANDS
#define  TX_COMMAND                   "AT+BLEUARTTX="
#define  RX_COMMAND                   "AT+BLEUARTRX"
#define  DEVICE_NAME_COMMAND          "AT+GAPDEVNAME=Shot Trainer-Arm Module 2"

// HARDWARE UART SETTINGS
#ifdef Serial1    // this makes it not complain on compilation if there's no Serial1
  #define BLUEFRUIT_HWSERIAL_NAME     Serial1
#endif

// SHARED SPI SETTINGS
#define BLUEFRUIT_SPI_CS              (8)
#define BLUEFRUIT_SPI_IRQ             (7)
#define BLUEFRUIT_SPI_RST             (4)

// ASSORTED CONSTANTS
#define  BAUD_RATE                    (115200)
#define  PER_SEC                      (10)
#define  WAIT_TIME                    (1000 / PER_SEC)
#define  DATA_FACTOR                  (32.0)
#define  I2C_PORT                     (55)

#endif

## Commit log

2021-09-21 Initial Repo
    [#Resources.xlsx, p21014.kicad_pcb, p21014.sch]
2021-09-21 Refactor Project for Additional People
    [#Resources.xlsx]
2021-09-21 Added Initial Components to RevA Board
    [p21014.sch]
2021-09-21 Restructure Board, Added Sheets and Layout to RevA
    [IMU.sch, microcontroller.sch, p21014.sch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]
2021-09-21 Added Microcontroller Logic to RevA
    [microcontroller.sch, p21014.sch]
2021-09-21 Finished Rough RevA and Added Annotations
    [IMU.sch, microcontroller.sch, p21014.sch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]
2021-09-21 Added Footprints to RevA 1/2
    [IMU.sch, microcontroller.sch, p21014.sch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]
2021-09-21 Removed Irrelevant Custom Footprints
2021-09-22 Added Feather Board Project as Reference
    [Adafruit Feather M0 WiFi.brd, Adafruit Feather M0 WiFi.kicad_pcb, Adafruit Feather M0 WiFi.sch]
2021-09-23 Added \CAD Folder
2021-09-26 Updated Power Pins and Header Layout
    [#Resources.xlsx, IMU.sch, microcontroller.sch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]
2021-09-26 Created Female Pin Header Footprints
    [microcontroller.sch]
2021-09-27 Added Basic PCB Layout
2021-09-27 Added All Proper Footprints to Layout
    [keystone-PN1027.STEP, p21014.kicad_pcb]
2021-09-27 Add \CAD\Old STP Files
    [#Resources.xlsx, Arm_Single.STL]
2021-09-27 Finished Layout RevA Board
    Still needs routing.
    [p21014.kicad_pcb]
2021-09-27 Completely Finished RevA Board
    [p21014-B_Cu.gbr, p21014-B_Mask.gbr, p21014-B_Paste.gbr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]
2021-09-27 File Backup Updates
    [#Resources.xlsx]
2021-09-27 Updated RevA Parts List/Digikey Order 1
    [#Resources.xlsx, p21014.kicad_pcb]
2021-09-28 Added Old .SLDPRT Files
    [#Resources.xlsx, Arm_Single - no notch.SLDPRT, Arm_Single.SLDPRT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]
2021-09-28 Uploaded RevB Board Template
    Copied /RevA to /RevB and removed schematic components from .pcbnew (in RevB).
    [IMU.sch, microcontroller.sch, p21014.dsn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]
2021-09-28 Updated RevB Schematic
    [IMU.sch, microcontroller.sch, p21014.sch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]
2021-09-28 Roughed out RevB PCB layout
    [p21014.kicad_pcb]
2021-09-30 Finished RevB Layout
    [p21014.kicad_pcb]
2021-09-30 Uploaded Wearable-R0 CAD Files
    [Wearable-R0.SLDPRT, Wearable-R0.STL]
2021-09-30 Auto-routed RevB
    [p21014.dsn, p21014.kicad_pcb]
2021-09-30 Created RevB Gerber Files
    [p21014-B_Cu.gbr, p21014-B_Mask.gbr, p21014-B_Paste.gbr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]
2021-09-30 Updated RevB/Order 1
    (Digikey)
    [#Resources.xlsx]
2021-09-30 Fixed Resources.xlsx, Correct 6 Pin Header
    [#Resources.xlsx]
2021-09-30 Updated RevB 3D Models
    [91601-306LFc.stp, 91601-308LFc.stp, 91601-412ALFc.stp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]
2021-09-30 Rearranged RevB CAD
    [p21014.SLDASM, p21014.kicad_pcb, p21014_RevB - p21014.step-1 91601-306LFc.step-1 SOLID-3.step-1.STL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]
2021-09-30 Added Feather M0 Board CAD
    [Adafruit M0 AT1500 Feather_000.SLDPRT]
2021-09-30 Added Full Assembly of RevB Electronics Construction
    [68001-x06.SLDPRT, 68001-x06.prt, Adafruit_BNO055.SLDPRT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]
2021-09-30 Added /RevC Board
    [IMU.sch, microcontroller.sch, p21014.dsn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]
2021-09-30 [ImgBot] Optimize images
    *Total -- 4,026.54kb -> 3,782.51kb (6.06%)
    /CAD/Adafruit BNO055/bottom.jpg -- 97.76kb -> 87.93kb (10.06%)
    /CAD/Adafruit BNO055/top.jpg -- 1,779.22kb -> 1,615.60kb (9.2%)
    /CAD/Adafruit BNO055/Renderings/Render.png -- 1,110.28kb -> 1,071.89kb (3.46%)
    /CAD/Adafruit BNO055/Renderings/Render2.png -- 1,039.28kb -> 1,007.09kb (3.1%)
2021-09-30 Fixed RevC Layout Alignment
    [p21014.kicad_pcb]
2021-10-04 Added Files to Produce RevC Board
    [p21014.dsn]
2021-10-04 Fixed RevC Outline and STP/DSN
    [RevC_Electrical_Assembly.SLDASM, p21014.dsn, p21014.kicad_pcb]
2021-10-04 Updated IMU Mounting Location for RevC
    [RevC_Electrical_Assembly.SLDASM, p21014.kicad_pcb]
2021-10-04 Confirmed RevC Mating
    [RevC_Electrical_Assembly.SLDASM, SOLID-0.step.SLDPRT, SOLID-1.step.SLDPRT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]
2021-10-04 Completed RevC Routing
    [SOLID-0.step.SLDPRT, SOLID-1.step.SLDPRT, SOLID-2.step.SLDPRT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]
2021-10-04 Added RevC Gerber Files
    [p21014-B_Cu.gbr, p21014-B_Mask.gbr, p21014-B_Paste.gbr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]
2021-10-05 Added Working BLE Driver
2021-10-05 Added IMU to RevC_1 Driver
2021-10-05 Finished RevC_1 Driver
2021-10-05 Fixed Code Flow of RevC_1.ino BLE Startup
    [RevC_1.ino]
2021-10-07 Reorganized .ino File Structure for Arm-Viewer. Also created RevC_2
2021-10-07 Fixed send_data issue with 0s
    [RevC_2.ino, ShotTrainer.h]
2021-10-15 Added LED Control to Wearable
2021-10-18 Accidental Footprints
2021-10-19 Added driver for Mercy's testing
2021-10-29 Updated CAD wearable
    [Wearable-R0.SLDPRT]
2021-11-01 Updated RevC_Mercy to Match LED Restrictions
2021-11-08 fixed the camera
2021-11-09 Update #Resources.xlsx
    Digikey Order 2
    [#Resources.xlsx]

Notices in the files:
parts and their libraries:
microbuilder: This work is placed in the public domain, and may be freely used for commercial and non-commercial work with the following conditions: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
